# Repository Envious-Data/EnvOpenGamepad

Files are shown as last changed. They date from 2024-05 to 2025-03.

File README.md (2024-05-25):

# EnvOpenGamepad
 An open source gamepad using a RP2040 designed to be like popular gamepads but with a few bonus features and ease of repairability.

## Planned features
- layout similar to popular models
- additional buttons over popular models
- turbo mode
- hall effect sticks and triggers

## Features I want but cant implement (yet?)
- vibration/rumble
- wireless
- touchpad?

## Why

no real reason, I had this idea bouncing around in my head for ages so to procrastinate on other projects ill work on this one till I procrastinate on this one by working on others but really I just enjoy designing and making things and if they serve as a good example to do something whilst also helping me learn then its doing one of its main jobs.

I generally like things that can be repaired so if I can make something that surpasses a commercially avaliable example while being reasonable in cost then thats great because I really dont like not being able to repair things which is sometimes the case for commercially avaliable solutions.

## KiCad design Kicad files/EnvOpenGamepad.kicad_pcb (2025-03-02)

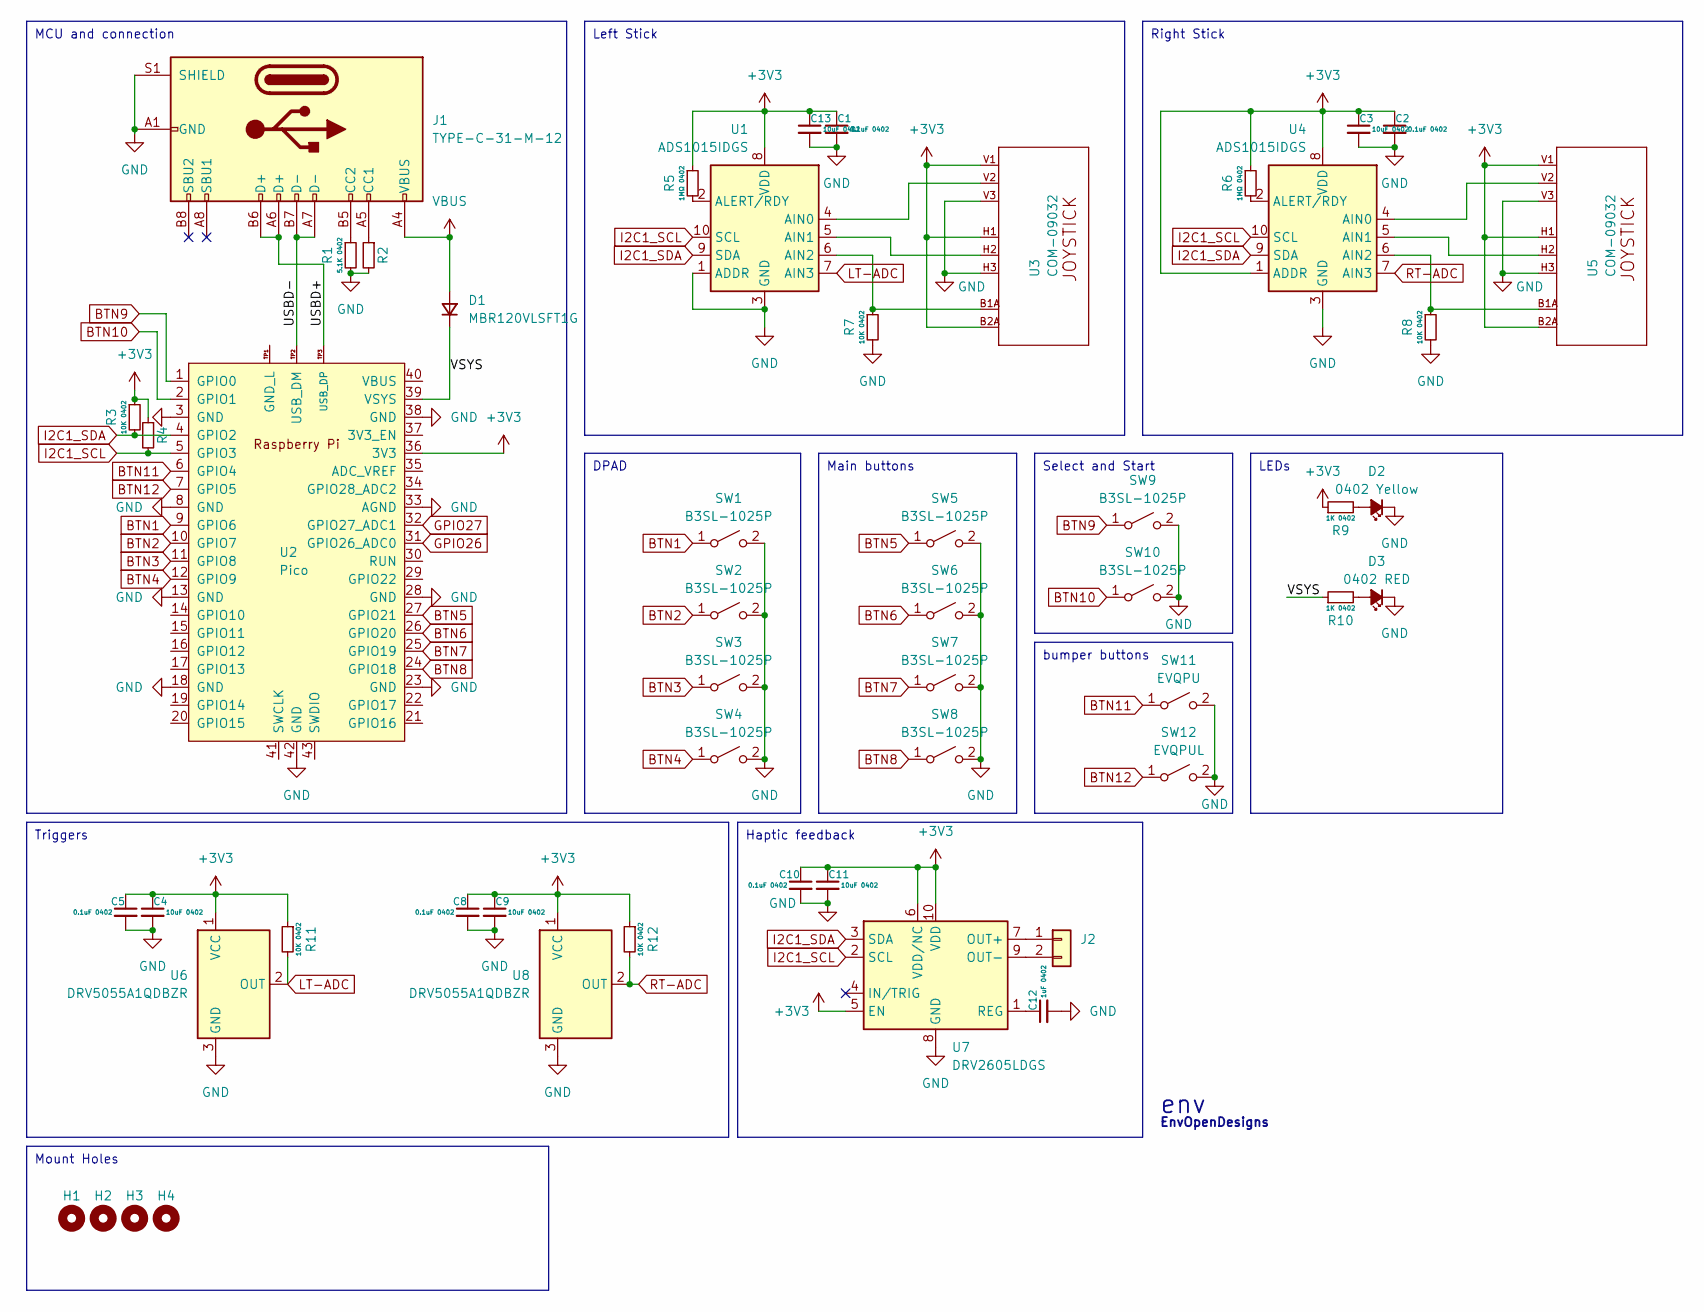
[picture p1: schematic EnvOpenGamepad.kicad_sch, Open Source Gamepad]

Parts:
C1, C2, C5, C8, C10: 0.1uF 0402; C_0402_1005Metric
C3, C4, C9, C11, C13: 10uF 0402; C_0402_1005Metric
C12: 1uF 0402; C_0402_1005Metric
D1: MBR120VLSFT1G; D_SOD-123F
D2: 0402 Yellow; LED_0402_1005Metric
D3: 0402 RED; LED_0402_1005Metric
H1, H2, H3, H4: M2 Mounting Hole; MountingHole_2.2mm_M2
J1: TYPE-C-31-M-12; USB_C_Receptacle_HRO_TYPE-C-31-M-12
J2: 01x02 2.54mm pin header; PinHeader_1x02_P2.54mm_Vertical
R1, R2, R4: 5.1K 0402; R_0402_1005Metric
R3, R7, R8, R11, R12: 10K 0402; R_0402_1005Metric
R5, R6: 1MΩ 0402; R_0402_1005Metric
R9, R10: 1K 0402; R_0402_1005Metric
SW1, SW2, SW3, SW4, SW5, SW6, SW7, SW8, SW9, SW10: B3SL-1025P; SW_SPST_B3SL-1022P
SW11: EVQPU; Panasonic_EVQPUL_EVQPUC
SW12: EVQPUL; Panasonic_EVQPUL_EVQPUC
U1, U4: ADS1015IDGS; TSSOP-10_3x3mm_P0.5mm
U2: Pico; RPi_Pico_SMD_TH
U3, U5: COM-09032; JOYSTICK
U6, U8: DRV5055A1QDBZR; SOT-23
U7: DRV2605LDGS; VSSOP-10_3x3mm_P0.5mm

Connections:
+3V3: C1.1, C2.1, C3.1, C4.1, C5.1, C8.1, C9.1, C10.1, C11.1, C13.1, R3.1, R4.1, R5.1, R6.1, R9.1, R11.1, R12.1, U1.8 (VDD), U2.36 (3V3), U3.B2A (SEL-), U3.H1 (H+), U3.V1 (V+), U4.1 (ADDR), U4.8 (VDD), U5.B2A (SEL-), U5.H1 (H+), U5.V1 (V+), U6.1 (VCC), U7.5 (EN), U7.6 (VDD/NC), U7.10 (VDD), U8.1 (VCC)
/USBD+: J1.A6 (D+), J1.B6 (D+), U2.TP3 (USB_DP)
/USBD-: J1.A7 (D-), J1.B7 (D-), U2.TP2 (USB_DM)
/VSYS: D1.1 (K), R10.1, U2.39 (VSYS)
BTN1: SW1.1 (A), U2.9 (GPIO6)
BTN2: SW2.1 (A), U2.10 (GPIO7)
BTN3: SW3.1 (A), U2.11 (GPIO8)
BTN4: SW4.1 (A), U2.12 (GPIO9)
BTN5: SW5.1 (A), U2.27 (GPIO21)
BTN6: SW6.1 (A), U2.26 (GPIO20)
BTN7: SW7.1 (A), U2.25 (GPIO19)
BTN8: SW8.1 (A), U2.24 (GPIO18)
BTN9: SW9.1 (A), U2.1 (GPIO0)
BTN10: SW10.1 (A), U2.2 (GPIO1)
BTN11: SW11.1 (A), U2.6 (GPIO4)
BTN12: SW12.1 (A), U2.7 (GPIO5)
GND: C1.2, C2.2, C3.2, C4.2, C5.2, C8.2, C9.2, C10.2, C11.2, C12.2, C13.2, D2.1 (K), D3.1 (K), J1.A1 (GND), J1.A12 (GND), J1.B1 (GND), J1.B12 (GND), J1.S1 (SHIELD), R1.2, R2.2, R7.2, R8.2, SW1.2 (B), SW2.2 (B), SW3.2 (B), SW4.2 (B), SW5.2 (B), SW6.2 (B), SW7.2 (B), SW8.2 (B), SW9.2 (B), SW10.2 (B), SW11.2 (B), SW12.2 (B), U1.1 (ADDR), U1.3 (GND), U2.3 (GND), U2.8 (GND), U2.13 (GND), U2.18 (GND), U2.23 (GND), U2.28 (GND), U2.33 (AGND), U2.38 (GND), U2.42 (GND), U3.H3 (H-), U3.V3 (V-), U4.3 (GND), U5.H3 (H-), U5.V3 (V-), U6.3 (GND), U7.8 (GND), U8.3 (GND)
GPIO26: U2.31 (GPIO26_ADC0)
GPIO27: U2.32 (GPIO27_ADC1)
I2C1_SCL: R4.2, U1.10 (SCL), U2.5 (GPIO3), U4.10 (SCL), U7.2 (SCL)
I2C1_SDA: R3.2, U1.9 (SDA), U2.4 (GPIO2), U4.9 (SDA), U7.3 (SDA)
LT-ADC: R11.2, U1.7 (AIN3), U6.2 (OUT)
unnamed: D2.2 (A), R9.2
unnamed: D3.2 (A), R10.2
unnamed: J1.A5 (CC1), R2.1
unnamed: J1.B5 (CC2), R1.1
unnamed: J2.1, U7.7 (OUT+)
unnamed: J2.2, U7.9 (OUT-)
unnamed: U1.4 (AIN0), U3.V2 (V)
unnamed: U1.5 (AIN1), U3.H2 (H)
unnamed: R7.1, U1.6 (AIN2), U3.B1A (SEL+)
unnamed: R5.2, U1.2 (ALERT/RDY)
unnamed: U4.4 (AIN0), U5.V2 (V)
unnamed: U4.5 (AIN1), U5.H2 (H)
unnamed: R8.1, U4.6 (AIN2), U5.B1A (SEL+)
unnamed: R6.2, U4.2 (ALERT/RDY)
unnamed: C12.1, U7.1 (REG)
RT-ADC: R12.2, U4.7 (AIN3), U8.2 (OUT)
VBUS: D1.2 (A), J1.A4 (VBUS), J1.A9 (VBUS), J1.B4 (VBUS), J1.B9 (VBUS)

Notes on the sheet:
Main buttons
MCU and connection
bumper buttons
Triggers
Mount Holes
Left Stick
Haptic feedback
Right Stick
Select and Start
LEDs
DPAD
env
EnvOpenDesigns

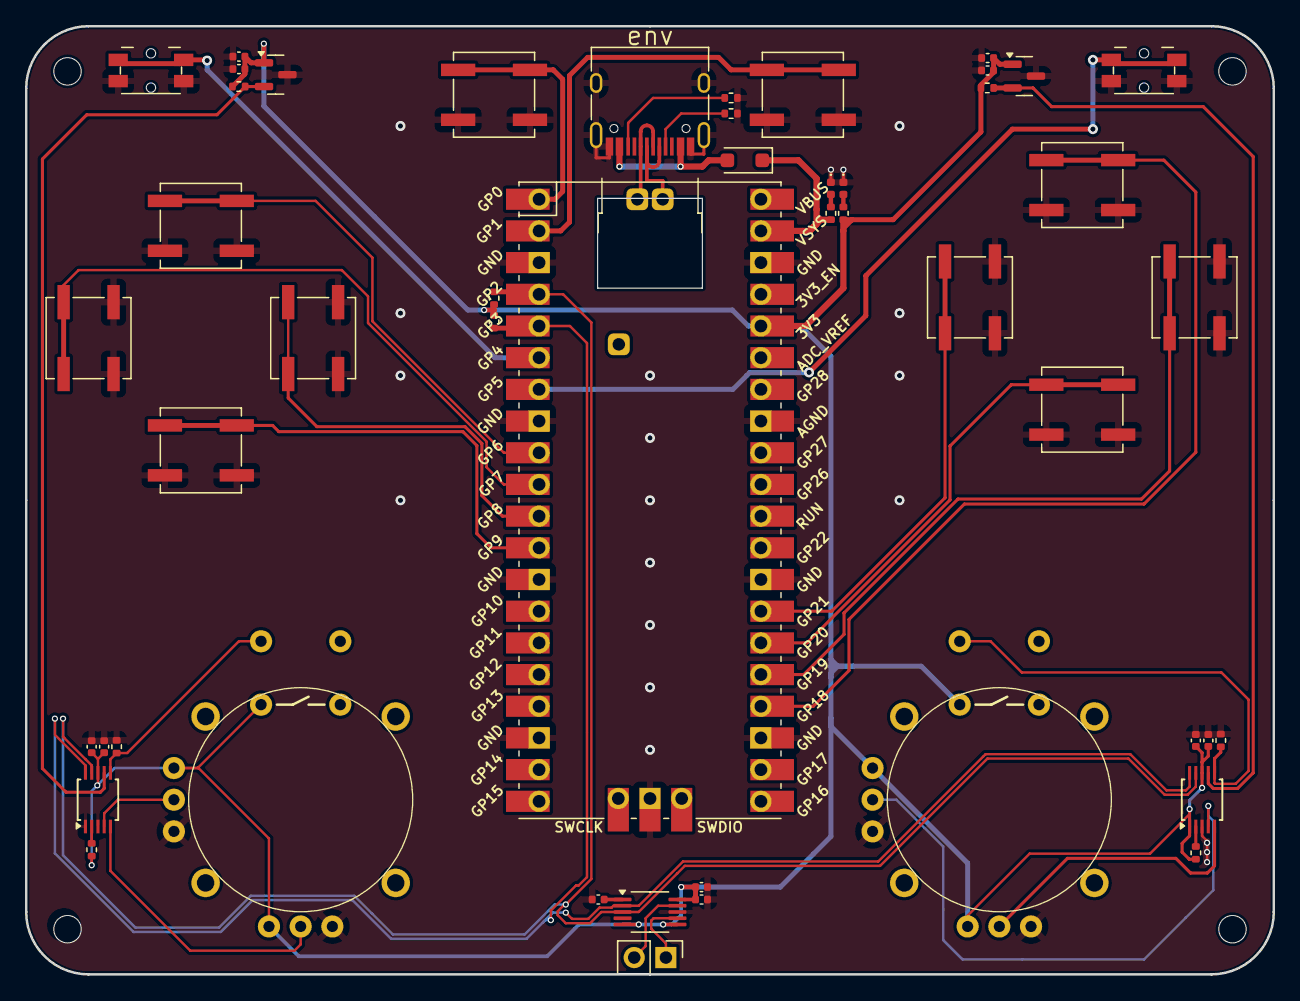
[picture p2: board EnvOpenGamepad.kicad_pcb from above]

Board: 2 copper layers, 100.0 x 76.0 mm, 52 parts (0 on the bottom side), 37 nets.

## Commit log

2024-09-23 completed schematic and started work on PCB
    [EnvOpenGamepad.kicad_pcb, EnvOpenGamepad.kicad_sch]
2025-02-04 updated schematic and completed pcb wiring, generated pcb production files.
    [EnvOpenGamepad.kicad_pcb, EnvOpenGamepad.kicad_sch]
2025-03-02 unsure of current changes
    [EnvOpenGamepad.kicad_pcb]
